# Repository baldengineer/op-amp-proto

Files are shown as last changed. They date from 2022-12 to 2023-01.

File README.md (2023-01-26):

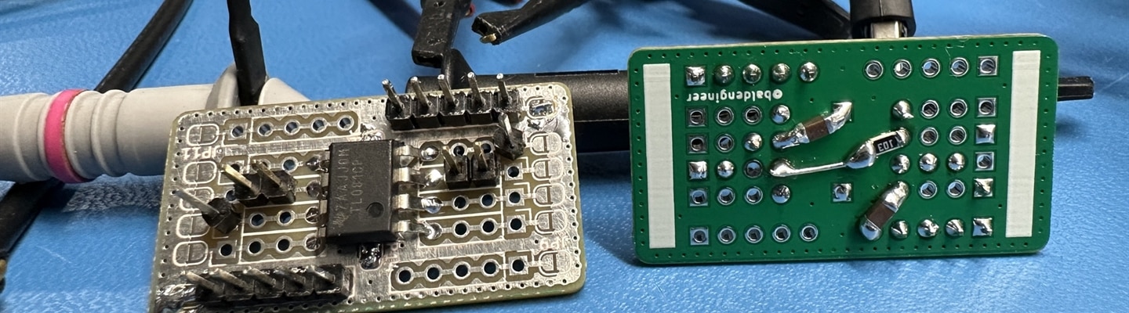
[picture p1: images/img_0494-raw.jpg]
TL081 Circuit with Op Amp Proto Board TL081 Circuit side-by-side


## Op Amp board for Prototyping and testing Op Amps
This board characterizes op amps in an SOIC-8 breakout board. The bottom layer is solid copper. The top has copper guard bands. There are solder jumps to connect the copper pours whatever pin is GND on the SOIC.

Turns out, if you bend the leads, version 1 can fit a DIP.

The "top" and "bottom" 2.54 mm holes are intended for power rails.

## Featured on ...
See the board in action in this element14 Present's Workbench Wednesdays video on [Slew Rate versus Rise Time](https://community.element14.com/challenges-projects/element14-presents/workbenchwednesdays/w/documents/27980/workbench-wednesdays-67-slew-rate-vs-rise-time-measureme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 "element14 Community").

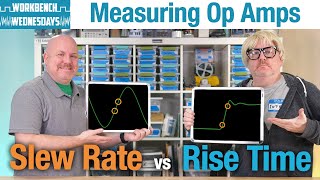
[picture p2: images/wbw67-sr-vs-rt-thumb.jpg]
Slew Rate versus Rise Time (for Op Amps) (https://youtu.be/xgTqjjBrfHQ "Bald Engineer on YouTube")


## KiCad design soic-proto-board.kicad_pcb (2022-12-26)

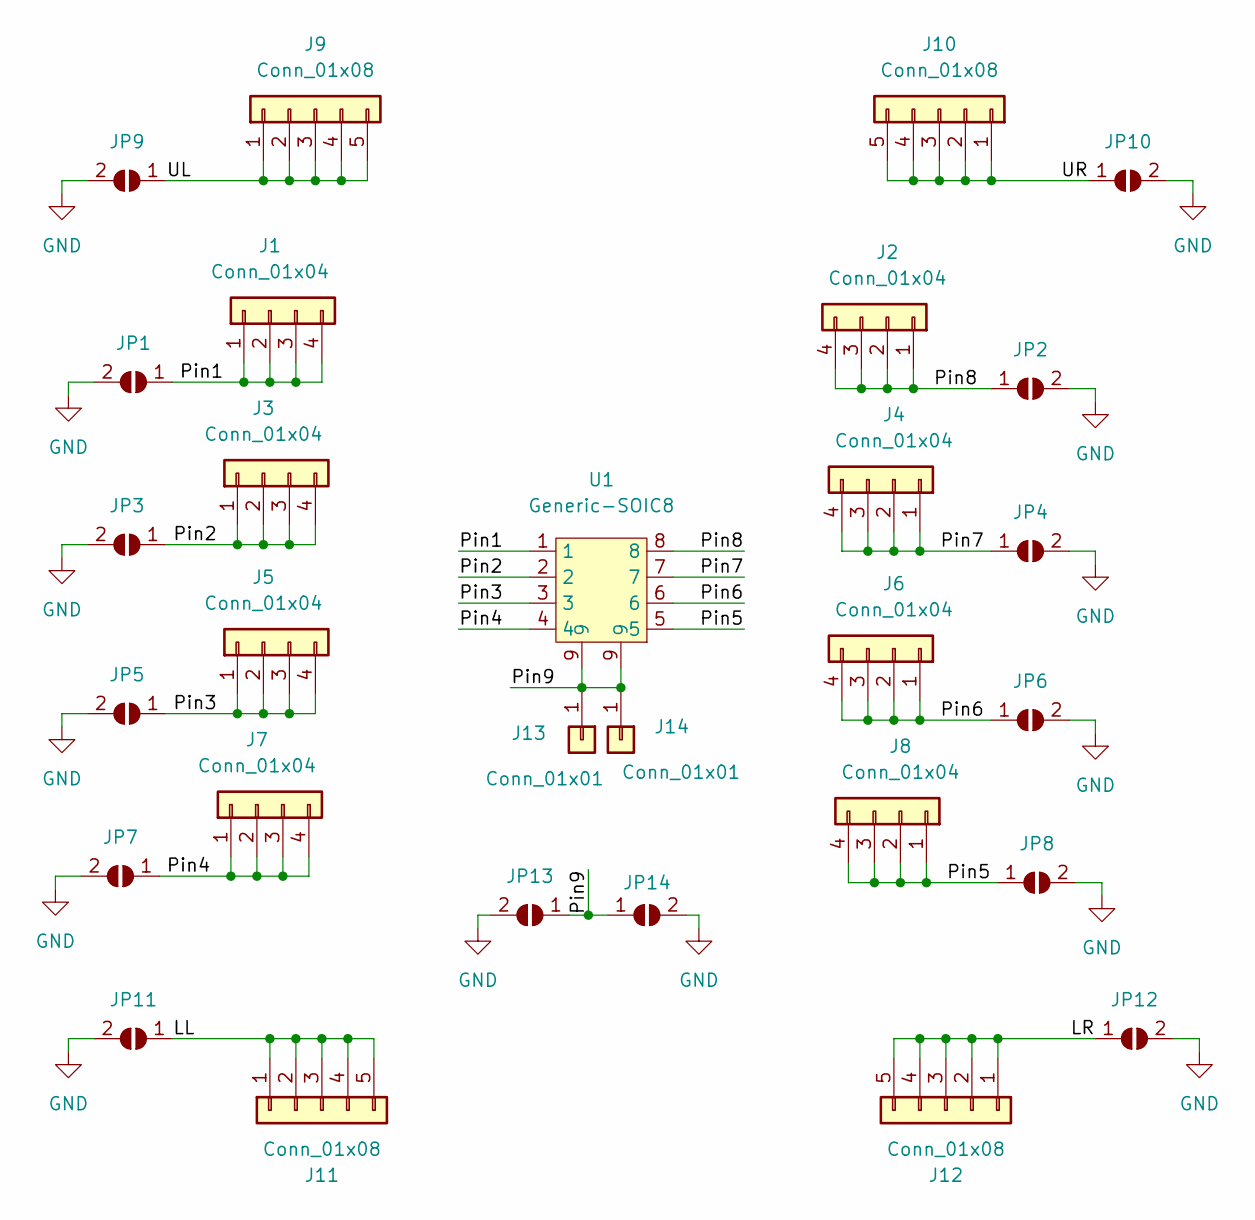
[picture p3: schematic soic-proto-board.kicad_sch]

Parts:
J1, J2, J3, J4, J5, J6, J7, J8: Conn_01x04; PinHeader_1x04_P2.54mm_Vertical
J9, J10, J11, J12: Conn_01x08; PinHeader_1x05_P2.54mm_Vertical
J13, J14: Conn_01x01; PinHeader_1x01_P2.54mm_Vertical
JP1, JP2, JP3, JP4, JP5, JP6, JP7, JP8, JP9, JP10, JP11, JP12, JP13, JP14: SolderJumper_2_Open; SolderJumper-2_P1.3mm_Open_RoundedPad1.0x1.5mm
U1: Generic-SOIC8; SOIC-8-1EP_3.9x4.9mm_P1.27mm_EP2.29x3mm

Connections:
/LL: J11.1, J11.2, J11.3, J11.4, J11.5, JP11.1 (A)
/LR: J12.1, J12.2, J12.3, J12.4, J12.5, JP12.1 (A)
/Pin1: J1.1, J1.2, J1.3, J1.4, JP1.1 (A), U1.1
/Pin2: J3.1, J3.2, J3.3, J3.4, JP3.1 (A), U1.2
/Pin3: J5.1, J5.2, J5.3, J5.4, JP5.1 (A), U1.3
/Pin4: J7.1, J7.2, J7.3, J7.4, JP7.1 (A), U1.4
/Pin5: J8.1, J8.2, J8.3, J8.4, JP8.1 (A), U1.5
/Pin6: J6.1, J6.2, J6.3, J6.4, JP6.1 (A), U1.6
/Pin7: J4.1, J4.2, J4.3, J4.4, JP4.1 (A), U1.7
/Pin8: J2.1, J2.2, J2.3, J2.4, JP2.1 (A), U1.8
/Pin9: J13.1, J14.1, JP13.1 (A), JP14.1 (A), U1.9
/UL: J9.1, J9.2, J9.3, J9.4, J9.5, JP9.1 (A)
/UR: J10.1, J10.2, J10.3, J10.4, J10.5, JP10.1 (A)
GND: JP1.2 (B), JP2.2 (B), JP3.2 (B), JP4.2 (B), JP5.2 (B), JP6.2 (B), JP7.2 (B), JP8.2 (B), JP9.2 (B), JP10.2 (B), JP11.2 (B), JP12.2 (B), JP13.2 (B), JP14.2 (B)

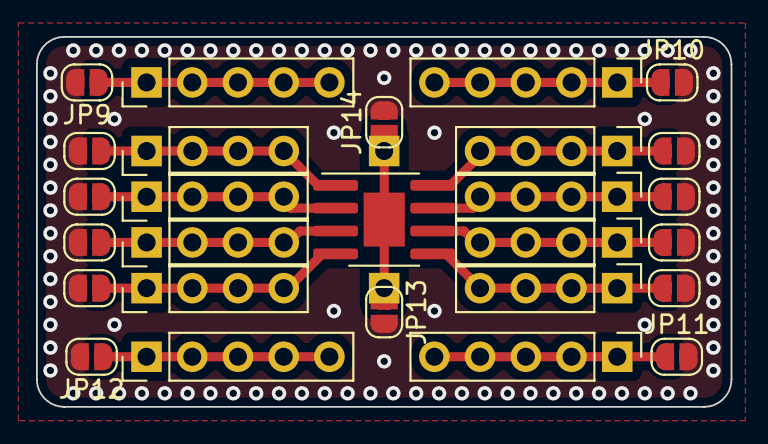
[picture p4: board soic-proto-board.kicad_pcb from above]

Board: 2 copper layers, 38.6 x 20.6 mm, 29 parts (1 on the bottom side), 14 nets.
